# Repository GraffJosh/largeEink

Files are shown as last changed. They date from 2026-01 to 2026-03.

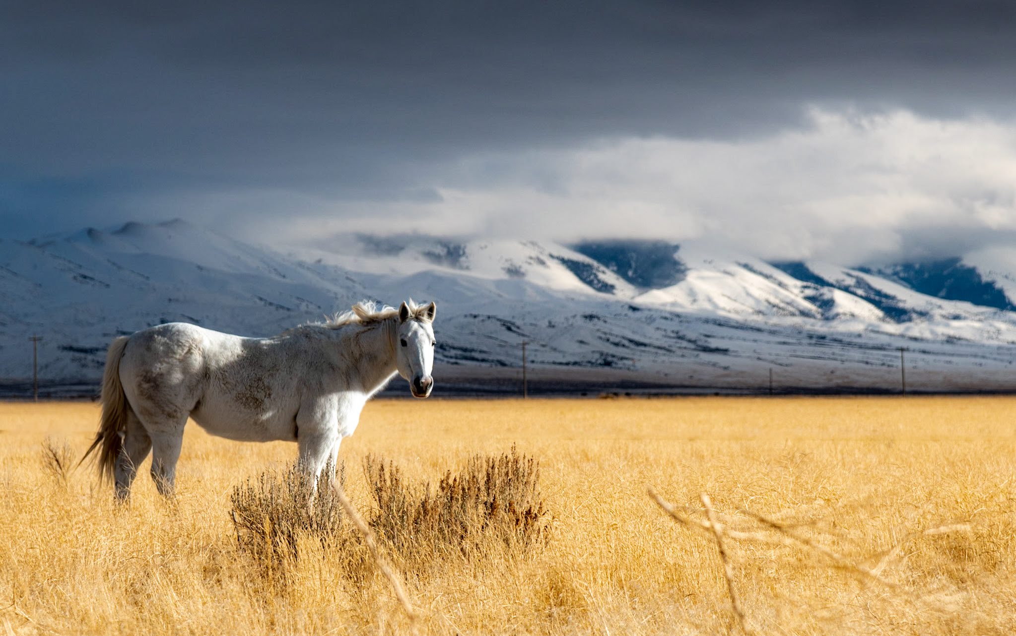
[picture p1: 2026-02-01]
imageServer/images/DSC_2975.jpg

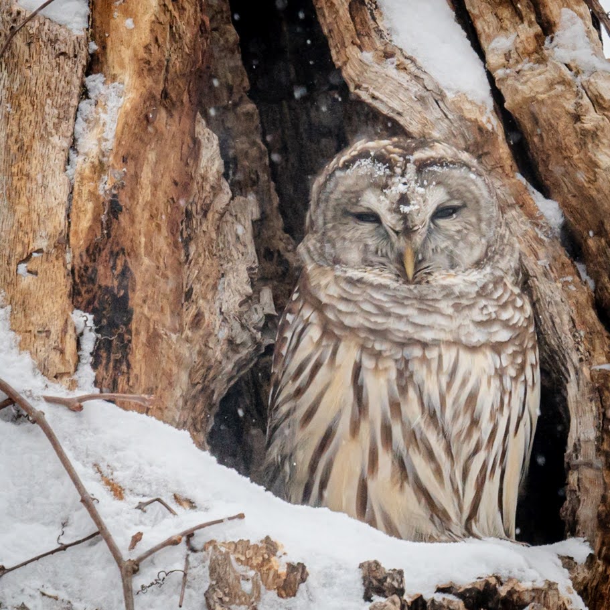
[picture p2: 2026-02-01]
imageServer/images/owl.jpg

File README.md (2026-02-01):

# largeEink — 7.5" E‑Paper Smart Display

Small project to drive a 7.5" grayscale e‑ink panel from an ESP32. Includes:
- An ESP32 firmware (eInkDriver.c) that fetches BMP images, converts to 4‑level grayscale with ordered dither + gamma LUT, and displays them on an e‑paper module.
- A Python helper (convertImage.py) to convert PNG/JPEG images into 4bpp C arrays for embedding.
- MQTT/Home Assistant integration for remote control.





Subscript: I don't like writing docs, so genAI helped with this page. If you're reading this, and you're a human a) I'm surprised you found my project b) I'm happy to help you implement this on your project. 

## Repository layout
- eInkDriver/  
  - eInkDriver.c — main ESP32 firmware
  - convertImage.py — Python tool to convert images to 4bpp C arrays
  - icons.h, secrets.h, other project files (expected)
- imageServer/
  - imageServer.py - serves images over HTTP to the esp32.
  - eInkImage.py - Helper class for the image server (

## Prerequisites
- Hardware: ESP32 board compatible with the e‑paper module used (pins in firmware), 7.5" e‑paper display.
- Toolchain: Arduino/PlatformIO or preferred ESP32 toolchain to compile and flash the C firmware.
- Python 3 + associated image libraris to run the conversion script.
  - Install: pip install pillow

## Configuration
- secrets.h — add WIFI_SSID, WIFI_PASS, MQTT_SERVER, MQTT_PORT, MQTT_USER, MQTT_PASSWORD and any URL constants (URL1, URL2, URL3, etc.).

## Using the Python image converter
Script: convertImage.py
Usage:
python3 convertImage.py <inputDirectory> <OutputFilename> <width> <height>

- inputDirectory: folder with .png/.jpg/.jpeg files.
- OutputFilename: path to the generated C header (appends arrays).
- width/height: desired target size to resize each image to.

The script writes PROGMEM C arrays and width/height constants for each image.

## Firmware behavior
- Downloads BMP image(s) from configured URLs, converts streamed BMP rows to 4bpp via a dithered/gamma LUT, and pushes rows to the display.
- Maintains persistent preferences (imageCount, displayIndex), Reducing unecessary flickering after deep sleep
- Exposes MQTT/Home Assistant entities for page selection, aux URL, refresh, and battery sensors (via HA-MQTT integration).
- Supports deep sleep wake via buttons and timer.

## MQTT / Home Assistant
- Device ID and friendly name defined in eInkDriver.c (HA_DEVICE_ID, HA_DEVICE_FRIENDLY_NAME).
- Provided entities include page selection, aux URL, refresh button and battery sensors. Configure your Home Assistant MQTT discovery or use the included HA‑MQTT helper to register entities.

## Troubleshooting
- BMP download: server must serve uncompressed BMP with expected resolution/pixel format.
- The driver must receive exactly 480x800 pixels image, in 8bit BMP format.

## Tips
- Make sure you setup your secrets file with the correct URLS and credentials for MQTT etc

## Future Work
- It would be cool to do partial updates or less flickering.
  - For example an indicator showing that it's thinking or working.

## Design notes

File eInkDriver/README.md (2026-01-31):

# E-Ink Smart Display Driver

A comprehensive Arduino firmware for an ESP32-based 7.5-inch e-ink display with Home Assistant integration, battery monitoring, and multi-page support.

## Overview

This project drives a large e-ink display with WiFi connectivity, Home Assistant MQTT support, and local image serving. The display supports grayscale dithering, battery-aware deep sleep, and button-controlled page navigation.

## Hardware Requirements

- **Microcontroller**: ESP32 (tested on variant with ADC)
- **Display**: 7.5-inch e-ink panel (800×480 resolution, 4-level grayscale) https://www.seeedstudio.com/TRMNL-7-5-Inch-OG-DIY-Kit-p-6481.html
- **Power**: 4.2V battery with voltage divider to ADC
- **Input**: 3 push buttons on GPIO pins
- **GPIO Pins**:
    - `BUTTON_1_PIN` (D1): Next page
    - `BUTTON_2_PIN` (D2): Refresh current page
    - `BUTTON_3_PIN` (D4): Previous page
    - `BATTERY_PIN` (GPIO1): Battery voltage ADC input
    - `ADC_EN_PIN` (GPIO6): ADC enable control
## Installation Example:



## Software Dependencies

### Arduino Libraries
- `WiFi.h` – Network connectivity
- `HTTPClient.h` – Download images and check updates
- `TFT_eSPI.h` – Display driver library
- `PubSubClient.h` – MQTT client
- `Preferences.h` – Persistent storage (ESP32 NVS)

### Custom Libraries
- `HaMqttEntities.h` – Home Assistant MQTT discovery & entities
- `driver.h` – E-ink display abstraction layer
- `icons.h` – Battery indicator icons (4bpp format)
- `secrets.h` – WiFi and MQTT credentials

## Configuration

### secrets.h Template
Create a `secrets.h` file in the sketch directory:

```cpp
#define WIFI_SSID "your-ssid"
#define WIFI_PASS "your-password"

#define MQTT_SERVER "192.168.1.100"
#define MQTT_PORT 1883
#define MQTT_USER "mqtt_user"
#define MQTT_PASSWORD "mqtt_password"

#define URL1 "http://your-server/path1" 
#define URL2 "http://your-server/path2"
#define URL3 "http://your-server/path3" (This URL is used to determine if there is an updated image; it should return a BMP image counter as plain text. The name should be updated eventually.)
#define URL4 "http://your-server/path4"

#define HA_URL_PREFIX "http://your-server/"
#define HA_URL_SUFFIX ""
#define HA_URL_DATA "default-page"
```

### Display Rotation
Modify `ROTATION` constant (0–3) to adjust display orientation.

## Features

### Multi-Page Display System
Three configurable pages:
- **Page 0 (Image)**: BMP image from server with periodic refresh
- **Page 1 (Home Assistant)**: Dashboard from HA instance
- **Page 2 (Auxiliary)**: Custom URL via MQTT

### Advanced Image Dithering
- **Ordered Bayer dithering** for smooth grayscale representation
- **Gamma correction** with 256-entry lookup table
- **Snap-to-level** logic prevents noise in flat UI areas
- Configurable dither strength (default 85/255)

### Battery Management
- Real-time voltage monitoring (30-sample averaging)
- Battery state classification:
    - `BATT_FULL` (≥4.0V)
    - `BATT_GOOD` (≥3.7V)
    - `BATT_MEDIUM` (≥3.5V)
    - `BATT_LOW` (≥3.2V)
    - `BATT_CRITICAL` (<3.2V)
- Battery icon overlay on display
- Automatic deep sleep when voltage <4.1V

### Deep Sleep & Power Management
- **Deep sleep duration**: 300 seconds (Image page), 200 seconds (others)
- **Wake triggers**: Button press or timer interrupt
- **Power conservation**: ADC disabled between reads, WiFi disconnects during sleep
- **Startup delay**: 20-second minimum awake time before sleep

### Home Assistant Integration
MQTT entities for:
- `page_select` – Page selection dropdown
- `aux_url` – Dynamic auxiliary URL
- `refresh_button` – Manual refresh trigger
- `battery_voltage` – Real-time voltage (V)
- `battery_state` – Battery percentage (%)

Device ID: `smart_display_5`

### Button Controls
- **Button 1**: Cycle to next page
- **Button 2**: Force refresh current page
- **Button 3**: Cycle to previous page
- **Debounce**: 250ms delay between presses

## Image Processing

### BMP Download & Conversion
1. Stream 24-bit BMP from HTTP server
2. Convert to grayscale per-pixel
3. Apply ordered dithering with gamma correction
4. Pack into 4-bit-per-pixel format
5. Push rows to display in reverse order

### Image Server Integration
- Checks server image counter for new content
- Only re-downloads when counter changes
- Image count stored in NVS to persist across reboots

## Building & Uploading

1. Install Arduino IDE with ESP32 board support
2. Add required libraries via Library Manager
3. Create `secrets.h` with your credentials
4. Configure pin assignments if different
5. Select appropriate ESP32 board variant
6. Upload sketch

## Persistent Storage (NVS)

- `displayIndex` – Current page number
- `imageCount` – Last-downloaded image counter

Access via `Preferences` API (namespace: `"myapp"`).

## Troubleshooting

| Issue | Solution |
|---|---|
| Display crashes on startup | Ensure e-ink init before WiFi init |
| WiFi timeout | Check 15-second timeout threshold |
| Dither artifacts | Adjust `SNAP_THRESH` or `DITHER_STRENGTH` |
| Battery reading unstable | Verify voltage divider resistor values |
| MQTT connection fails | Confirm broker address, user, and password |

## Future Enhancements

- Partial display updates for faster refresh
- Compressed image support
- Scheduled updates vs. timer-only
- Home Assistant automations (auto-switch pages)

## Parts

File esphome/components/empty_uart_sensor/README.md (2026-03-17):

```yaml
# example configuration:

sensor:
  - platform: empty_uart_sensor
    name: Empty UART sensor

uart:
  tx_pin: D0
  rx_pin: D1
  baud_rate: 9600
```

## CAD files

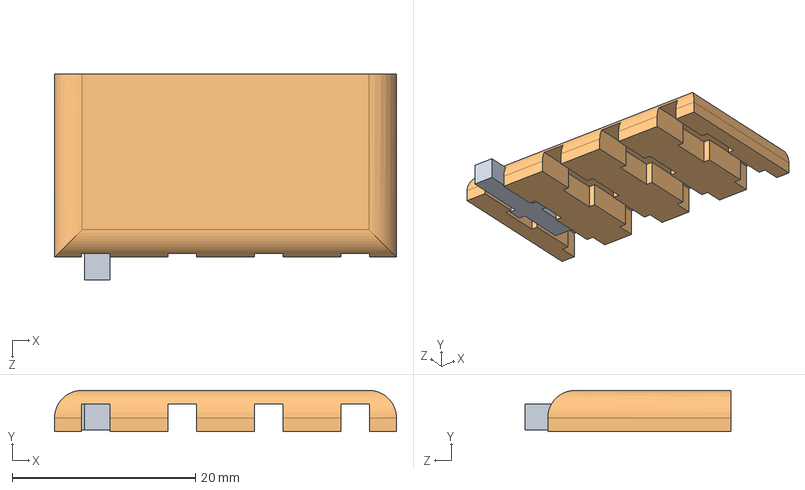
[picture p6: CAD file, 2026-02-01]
Button Pusher Assembly.SLDASM
37.3 x 4.50 x 22.5 mm
Button Adapter
Button

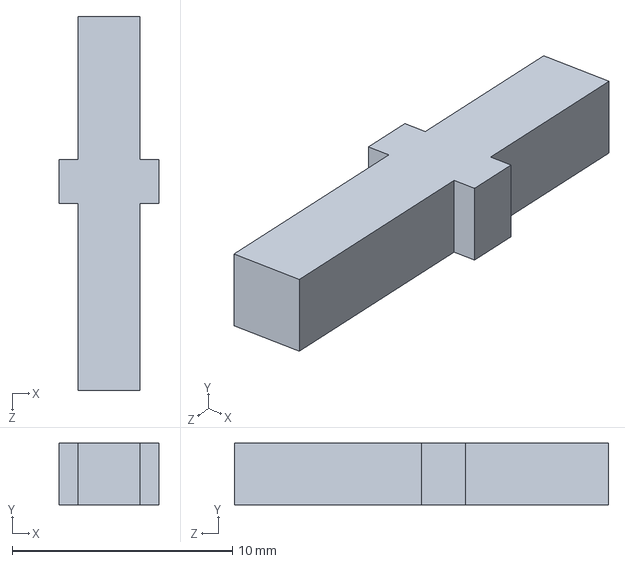
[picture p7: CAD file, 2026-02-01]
Button.SLDPRT
4.55 x 2.80 x 17.0 mm

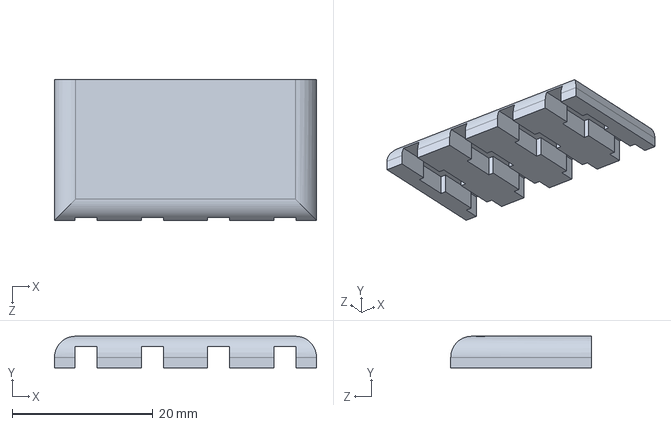
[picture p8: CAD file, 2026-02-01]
Button Adapter.SLDPRT
37.3 x 4.50 x 20.0 mm

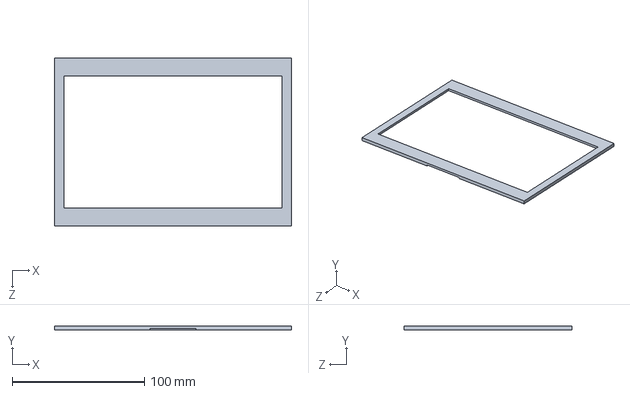
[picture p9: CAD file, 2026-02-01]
Frame Adapter.SLDPRT
179.0 x 3.00 x 127.0 mm

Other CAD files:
Button Adapter.STL
Button.STL
Frame Adapter.STL

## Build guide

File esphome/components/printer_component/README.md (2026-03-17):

```yaml
# example configuration:

empty_uart_component:
  id: empty_uart_component_1

uart:
  tx_pin: D0
  rx_pin: D1
  baud_rate: 9600
```

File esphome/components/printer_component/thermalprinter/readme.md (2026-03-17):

# Epson TM-T88II Library

A Library to control an Epson TM-T88II thermal printer (microprinter) by an arduino via serial connection.

## Requirements

To get Arduino work together with the thermal priner on RS232 (serial) you need a level shifter. From Maxim you can get MAX2XX chips for 5 Volt and MAX32XX for 3.3 volt powered arduinos. The library works with SoftSerial so you are still able to send Data to Arduino with the standard serial line. The SoftSerial works at 9600 baud.

## Tested

- Epson TM-T88II Model M129B (Serial RS232) & Arduino Uno & Maxim MAX233CPP

## Functions

The functions available in this class are:

### `Epson::Epson(int rxPin, int txPin)`

Constructor that initializes the `rxPin` and `txPin` used to communicate with the printer and calls the `start()` function.

### `void Epson::start()`

Sets up the communication pins, initializes the `SoftwareSerial` object used for communication with the printer, and sets the baud rate to 9600.

### `int Epson::getStatus()`

Sends a query to the printer to check its status. Returns `22` if the printer is online.

### `int Epson::read()`

Reads a single byte of data from the printer.

### `void Epson::feed(uint8_t n)`

Prints the data in the print buffer and feeds `n` lines of paper.

### `void Epson::feed()`

Equivalent to calling `feed(1)`.

### `void Epson::lineSpacing(uint8_t n)`

Sets the line spacing to `n/180` inch.

### `void Epson::defaultLineSpacing()`

Sets the line spacing to `1/6` inch, which is equivalent to 30 dots.

### `void Epson::characterSet(uint8_t n)`

Selects an international character set based on the value of `n`. See reference for more metails.

Example:

```
 0 = U.S.A.
 1 = France
 2 = Germany
 3 = U.K.
 4 = Denmark I
 5 = Sweden
 6 = Italy
 7 = Spain
 8 = Japan
 9 = Norway
10 = Denmark II
```

### `void Epson::doubleHeightOn()`

Enables double-height text printing.

### `void Epson::doubleHeightOff()`

Disables double-height text printing.

### `void Epson::boldOn()`

Enables bold text printing.

### `void Epson::boldOff()`

Disables bold text printing.

### `void Epson::underlineOn()`

Enables underlined text printing.

### `void Epson::underlineOff()`

Disables underlined text printing.

### `void Epson::reverseOn()`

Enables white/black reverse printing mode.

### `void Epson::reverseOff()`

Disables white/black reverse printing mode.

### `void Epson::justifyLeft()`

Sets text justification to left.

### `void Epson::justifyCenter()`

Sets text justification to center.

### `void Epson::justifyRight()`

Sets text justification to right.

### `void Epson::barcodeHeight(uint8_t n)`

Sets the height of barcodes to `n` dots. Range 1-255.

### `void Epson::barcodeWidth(uint8_t n)`

Sets the width of barcodes to `n` dots. Range 2-6

### `void Epson::barcodeNumberPosition(uint8_t n)`

Sets the position of the barcode number. Range 0-3

### `void Epson::printBarcode(uint8_t m, uint8_t n)`

Prints a barcode of type `m` (range 65-73) with a digit length of `n`.

### `void Epson::cut()`

Performs a full cut of the paper.

### `size_t Epson::write(uint8_t c)`

Writes a single byte of data to the printer.

## Inspiration

- [Tom Taylor · Post Microprinter](https://web.archive.org/web/20130116063826/http://tomtaylor.co.uk/projects/microprinter)
- [Tom Taylor · Code for the microprinter project](https://github.com/tomtaylor/microprinter-arduino)
- [Roo Reynolds · Post Microprinter](http://rooreynolds.com/2009/02/01/microprinter/)
- [Roo Reynolds · Microprinter Arduino library, Java and Ruby API](https://github.com/rooreynolds/microprinter)
- [Adafruit · Mini Thermal Receipt Printers](https://learn.adafruit.com/mini-thermal-receipt-printer)
- [Adafruit · Thermal Printer Library](https://github.com/adafruit/Adafruit-Thermal-Printer-Library/)

## Contributors

- [docwisdom](https://github.com/docwisdom)
- [signalwerk](https://github.com/signalwerk)

Contributions appreciated.

## License

You may use this work under the terms of either the MIT License or the GNU General Public License (GPL) Version 3

## History

- 2023-03-02 - Add a documentation of the class to the readme.md
- 2014-11-24 - include functionality for reading printer status, printing barcodes and justification
- 2012-04-13 - first public release
- 2012-03-13 - first beta of the class extracted for standalone
- 2010-06-05 – first public lecture with the code ([«Der Tag der Schrift»](http://www.typo-online.ch/tds/2010/))

### Keywords

thermal, micro, receipt, printer, serial, tm-t88, tm88, tmt88, epson

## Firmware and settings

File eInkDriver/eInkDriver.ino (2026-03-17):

#include <WiFi.h>
#include <HTTPClient.h>
#include "TFT_eSPI.h"
#include "driver.h"
#include <Preferences.h>
#include "secrets.h"
#include "icons.h"

#include<PubSubClient.h>
#include<HaMqttEntities.h>



Preferences prefs;
EPaper epaper;

const char* ssid = WIFI_SSID;
const char* password = WIFI_PASS;

const char* url1 = URL1;
const char* url2 = URL2;
const char* url3 = URL3;

const uint8_t ROTATION = 2; // Rotation of 2 rotates 180

#define SRC_W 800
#define SRC_H 480
#define DST_W 800
#define DST_H 480

#define BYTES_PER_ROW (DST_W / 2)
#define IMAGE_SIZE (BYTES_PER_ROW * DST_H)

// 256-entry lookup table
static uint8_t gammaLUT[256];
static const uint8_t bayer8[8][8] = {
 { 0,48,12,60, 3,51,15,63},
 {32,16,44,28,35,19,47,31},
 { 8,56, 4,52,11,59, 7,55},
 {40,24,36,20,43,27,39,23},
 { 2,50,14,62, 1,49,13,61},
 {34,18,46,30,33,17,45,29},
 {10,58, 6,54, 9,57, 5,53},
 {42,26,38,22,41,25,37,21}
};

uint32_t lastUpdateMs = 0, startupTime=0;
uint16_t updateCount = 0;
uint32_t imageCount = 0;
uint8_t displayIndex = 0;
bool freshBoot = true;
bool deepsleepEnabled = false;
bool imageUpdateComplete = true;
uint16_t deepSleepDurationSeconds = 300;

const float CALIBRATION_FACTOR = 0.968;
#define BATTERY_PIN 1       // GPIO1 (A0) - BAT_ADC
#define ADC_EN_PIN 6        // GPIO6 (A5) - ADC_EN

const int BUTTON_1_PIN = D1;  // First user button
const int BUTTON_2_PIN = D2;  // Second user button
const int BUTTON_3_PIN = D4;  // Third user button
volatile bool button1Pressed = false;
volatile bool button2Pressed = false;
volatile bool button3Pressed = false;
#define BUTTON_DEBOUNCE_TIME_MS 250

WiFiClient client;
PubSubClient mqtt_client(client);


enum PageSelection{
    PAGE_IMAGE,
    PAGE_HOMEASSISTANT,
    PAGE_AUX_PAGE,
    PAGE_NUMPAGES
};
const char * select_options[PAGE_NUMPAGES] PROGMEM = {
     "Image Page",
     "HA Page",
     "Aux Page"
     };
     
const char * page_urls[PAGE_NUMPAGES] PROGMEM = {
     URL2,
     URL1,
     URL4,
     };

enum BatteryState{
    BATT_FULL,
    BATT_GOOD,
    BATT_MEDIUM,
    BATT_LOW,
    BATT_CRITICAL,
}batteryStatus;

#define HA_DEVICE_ID            "smart_display_5"
#define HA_DEVICE_FRIENDLY_NAME "7.5in Epaper Smart Display"

#define ENTITIES_COUNT 5
HADevice ha_device = HADevice(HA_DEVICE_ID,HA_DEVICE_FRIENDLY_NAME,"1.0");
// HANumber haPageNumber = HANumber("page_num","Page Number",ha_device,1,100,1);
HASelect haPageSelect = HASelect("page_select","Page Select",ha_device,PAGE_NUMPAGES,select_options);
HAText haURL = HAText("aux_url","Aux URL",ha_device,150);
HAButton haRefreshButton = HAButton("refresh_button","Refresh Page",ha_device);
HASensorNumeric haBatteryVoltage = HASensorNumeric("battery_voltage","Battery Voltage",ha_device,"V",2);
HASensorNumeric haBatteryState = HASensorNumeric("battery_state","Battery State",ha_device,"%",0);
// HASensorBinary haDeepSleepActive = HASensorBinary("deep_sleep_active","Deep Sleep Active");
// HASensorBinary haDeviceOnline = HASensorBinary("device_online","Device Online");


int getPageIndexFromSelect(const char* receivedSelectState,const char** list, uint16_t listSize)
{
    for(int index=0;index<listSize;index++)
    {
        if(!strcmp(list[index],receivedSelectState))
        {
            return index;
        }
    }
    return -1;
}

/* Callback from HA-MQTT entities. It is called when an entity changes its state.

    Entity can be NULL when the received topic is not related to any entity.
    This is useful to handle other topics with the same mqtt client.
*/
void ha_callback(HAEntity *entity, char *topic, byte *payload, unsigned int length){
    // if(entity == &haPageNumber){
    //     Serial.printf("Changed number state to %d \n",haPageNumber.getState());
    // }
    // else 
    if(entity == &haPageSelect)
    {
        printf("HA Callback set %s\n",haPageSelect.getState());
        setDisplayIndex(haPageSelect.getState());
    }
    else if(entity == &haRefreshButton)
    {
        Serial.printf("Refresh Button Pressed\n");
        freshBoot = true;
    }
    else if(entity == &haURL)
    {
        String prefix(HA_URL_PREFIX);
        String suffix(HA_URL_SUFFIX);
        String data(haURL.getState());
        static String auxURL = (prefix + data + suffix);
        page_urls[PAGE_AUX_PAGE] = auxURL.c_str();
        Serial.printf("Loading new Aux URL: %s\n",page_urls[PAGE_AUX_PAGE]);
        haURL.setState(data.c_str());
        setDisplayIndex(PAGE_AUX_PAGE);
        freshBoot = true;
    }
    else
        Serial.println("Callback called from other subscription");

}

/*
 * Display index handles which page we're currently displaying. 
 * These helpers ensure that the value is stored in persistent memory
 * (to reduce boot up updates)
 */
int getDisplayIndex()
{
    return prefs.getInt("displayIndex",PAGE_HOMEASSISTANT);
}
void setDisplayIndex(const char* receivedSelectState)
{
    Serial.printf("Select state: %s\n",receivedSelectState);
    int pageIndex = getPageIndexFromSelect(receivedSelectState,select_options,PAGE_NUMPAGES);
    if(pageIndex == -1)
    {
        Serial.printf("Failed to extract page index from state?\n");
    }
    else
    {
        setDisplayIndex(pageIndex);
        Serial.printf("Page Index updated to: %d\n",pageIndex);
    }
}
void setDisplayIndex(PageSelection index)
{
    setDisplayIndex((int) index);
}
void setDisplayIndex(int index)
{
    prefs.putInt("displayIndex", index);
    haPageSelect.setState(select_options[index]);
}
void incrementDisplayIndex()
{
    int next_page = (getDisplayIndex()+1);
    if(next_page == PAGE_NUMPAGES)
    {
        next_page = 0;
    }
    setDisplayIndex(next_page);
    Serial.printf("Increment Page to: %d\n",(int)next_page);
}
void decrementDisplayIndex()
{
    int next_page = (getDisplayIndex()-1);
    if(next_page < 0)
    {
        next_page = PAGE_NUMPAGES - 1;
    }
    setDisplayIndex(next_page);
    Serial.printf("Decrement Page to: %d\n",(int)next_page);
}

/*
 * Helper functions to compute time for deepsleep
 */
constexpr uint64_t deepSleepSeconds(uint64_t s) {
  return s * 1000000ULL;
}
constexpr uint64_t deepSleepMinutes(uint64_t m) {
  return deepSleepSeconds(m * 60ULL);
}

//ISR for handling buttons
void IRAM_ATTR button1ISR()
{    
    button1Pressed = true; 
}
void IRAM_ATTR button2ISR()
{    
    button2Pressed = true; 
}
void IRAM_ATTR button3ISR()
{    
    button3Pressed = true; 
}

#define ADC_SAMPLES 30
#define ADC_COUNTS 4095.0
#define ADC_REF_VOLTAGE 3.6
#define VOLTAGE_DIVIDER 2.0
float readBatteryVoltage() {
    // Enable ADC
    digitalWrite(ADC_EN_PIN, HIGH);
    delay(10);  // Short delay to stabilize

    // Read 30 times and average for more stable readings
    long sum = 0;
    for(int i = 0; i < ADC_SAMPLES; i++) {
        sum += analogRead(BATTERY_PIN);
        delayMicroseconds(100);
    }

    // Disable ADC to save power
    digitalWrite(ADC_EN_PIN, LOW);

    // Calculate voltage
    float adc_avg = sum / (ADC_SAMPLES*1.0);
    float voltage = (adc_avg / ADC_COUNTS) * ADC_REF_VOLTAGE * VOLTAGE_DIVIDER * CALIBRATION_FACTOR;

    // Determine battery level
    if (voltage >= 4.0) {
        batteryStatus = BATT_FULL;
    } else if (voltage >= 3.7) {
        batteryStatus = BATT_GOOD;
    } else if (voltage >= 3.5) {
        batteryStatus = BATT_MEDIUM;
    } else if (voltage >= 3.2) {
        batteryStatus = BATT_LOW;
    } else {
        batteryStatus = BATT_CRITICAL;
    }
    haBatteryVoltage.setState(voltage);
    haBatteryState.setState(map(voltage,4.2,3.1,100,0));
    return voltage;
}
// Call this once in setup() to initialize the LUT
void setupGammaLUT(float gamma = 0.4) {
    for (int i = 0; i < 256; i++) {
        float normalized = i / 255.0f;             // 0..1
        float corrected = pow(normalized, 1.0f / gamma);  // gamma correction
        uint8_t level = corrected * 4;             // 0..3
        if (level > 3) level = 3;                  // clamp
        gammaLUT[i] = level;
    }
}
// Nominal centers of each gray level (tune if needed)
#define G0  0     // black
#define G1  85    // dark gray
#define G2  170   // light gray
#define G3  255   // white

#define SNAP_THRESH 1   // +/- range to lock in (tune this!)

uint8_t ditheredLevel(uint8_t gray, int x, int y)
{
    // ----- PHASE 1: SNAP INPUT VALUES TO KNOWN-GOOD LEVELS -----
    // If the incoming pixel value is already very close to one of the
    // canonical gray centers (black, dark gray, light gray, white),
    // we lock it to that level immediately and skip dithering entirely.
    //
    // This prevents dithering noise in flat areas like text, icons,
    // UI backgrounds, and large uniform regions.
    if (abs(gray - G0) <= SNAP_THRESH) return 0;  // Near black → force black
    if (abs(gray - G1) <= SNAP_THRESH) return 1;  // Near dark gray → force level 1
    if (abs(gray - G2) <= SNAP_THRESH) return 2;  // Near light gray → force level 2
    if (abs(gray - G3) <= SNAP_THRESH) return 3;  // Near white → force white

    // ----- PHASE 2: ORDERED DITHER THRESHOLD LOOKUP -----
    // Look up a value from the 8×8 Bayer matrix using the pixel's (x, y)
    // coordinates. The "(x + y)" term decorrelates columns so that
    // vertical banding does not appear on the e-ink panel.
    //
    // The Bayer matrix values are in the range 0–63.
    int t = bayer8[y & 7][(x + y) & 7];

    // Shift the Bayer value so it is centered around zero.
    // This converts the range:
    //     0–63  →  -32…+31
    //
    // Centering is important so the dither adds *positive and negative*
    // bias evenly around the original pixel value.
    t -= 32;

    // ----- PHASE 3: APPLY DITHER AS A SMALL BIAS -----
    // Each output gray level is separated by ~85 (255 / 3).
    // We scale the dither so it nudges the pixel by roughly ±½
    // of one quantization step (~±42).
    //
    // This is enough to push pixels across level boundaries
    // without creating visible structure or banding.
    int adjusted = gray + (t * 85) / 64;

    // Clamp the adjusted value to the valid 8-bit grayscale range
    // to prevent underflow or overflow.
    if (adjusted < 0)   adjusted = 0;
    if (adjusted > 255) adjusted = 255;

    // ----- PHASE 4: SNAP AGAIN AT THE EXTREMES -----
    // After dithering, the adjusted value might drift slightly
    // into or out of the black/white regions. We re-snap here
    // to ensure that true blacks and whites remain stable and
    // do not acquire dither noise at their edges.
    if (adjusted <= G0 + SNAP_THRESH) return 0;  // Force black
    if (adjusted >= G3 - SNAP_THRESH) return 3;  // Force white

    // ----- PHASE 5: FINAL QUANTIZATION -----
    // Convert the final 8-bit grayscale value into one of the
    // 4 e-ink gray levels (0–3) using the gamma correction LUT.
    //
    // This LUT handles panel-specific response nonlinearity.
    return gammaLUT[adjusted];
}

void downloadAndConvertBMP(const char* url) {
    
    HTTPClient http;
    Serial.println("Starting BMP Download and Conversion.");
    http.setTimeout(60000);  // 30 seconds
    // http.setBufferSize(1024);  // or smaller
    http.setReuse(false);
    http.setRedirectLimit(10);
    http.begin(client, url);
    int code = http.GET();
    if (code != 200) {
        Serial.printf("HTTP GET failed: %d\n", code);
        Serial.printf("Content-Length: %d\n", http.getSize());
        Serial.printf("HTTP Code: %d\n", code);
        Serial.printf("Transfer-Encoding: %s\n", http.header("Transfer-Encoding").c_str());
        http.end();
        return;
    }

    WiFiClient* stream = http.getStreamPtr();
    if (!stream) {
        Serial.println("Failed to get stream");
        http.end();
        return;
    }

    uint8_t junk[32];
    // Read BITMAPFILEHEADER (14 bytes)
    uint8_t fileHeader[14];
    if (stream->readBytes(fileHeader, 14) != 14) {
        Serial.println("Failed to read BMP file header");
        return;
    }

    // Extract pixel data offset
    uint32_t bfOffBits = *(uint32_t*)&fileHeader[10];

    // We already consumed 14 bytes
    uint32_t toSkip = bfOffBits - 14;

    // Skip DIB header + palette (whatever size)
    while (toSkip > 0) {
        uint16_t n = stream->readBytes(junk, min(toSkip, (uint32_t)sizeof(junk)));
        if (n == 0) {
            Serial.println("Failed skipping BMP header/palette");
            return;
        }
        toSkip -= n;
    }

    // Process row by row
    uint16_t rowStride = (SRC_W + 3) & ~3; // BMP row padded to 4 bytes
    uint16_t padding = rowStride - SRC_W;
    // Row buffer
    static uint8_t grayRow[SRC_W];
    static uint8_t row4bpp[DST_W/2];
    static uint8_t level0 = 0;
    static uint8_t level1 = 0;
    static uint8_t packed = 0;
    // Read the BMP Image row by row, starting from the bottom. 
    for (int y = 0; y < DST_H; y++) {
        // 1. Read one BMP row into grayRow[SRC_W]
        stream->readBytes(grayRow, SRC_W);
        
        /* 2. Convert 2x8-bit → 2x4-level → 4bpp packed
        *      This is confusing, but it is a proprietary (and perhaps industry) standard for
        *      packing images for the Eink. The library mandates 4 bits per pixel, even though 
        *      it is only 2 bits of information (4 levels of gray)
        */
        for (int x = 0; x < DST_W; x += 2) {
        //    uint8_t level0 = gammaLUT[grayRow[x]];       // first pixel
        //    uint8_t level1 = gammaLUT[grayRow[x + 1]];   // second pixel
        //    uint8_t packed = (level0 << 4) | (level1 & 0x0F); // pack 2 pixels into 1 byte
        //    row4bpp[x / 2] = packed;

            level0 = ditheredLevel(grayRow[x],     x,     y);
            level1 = ditheredLevel(grayRow[x + 1], x + 1, y);

            packed = (level0 << 4) | (level1 & 0x0F);
            row4bpp[x / 2] = packed;
        }
        
        // 3. Push this row to the display in reversed y order
        epaper.pushImage(0, DST_H - 1 - y, DST_W, 1, (uint16_t*) row4bpp, 4);
        if (y % 100 == 0) Serial.printf("Processed row %d\n", y);
        
        // 4. Skip padding. This is poorly tested, because most rows aren't padded.
        if (padding) {
            stream->readBytes(junk, padding);
        }
    }
    addBatteryIndicator();
    //Write to the display
    epaper.update();
    
    // updateScreenInChunks(128);
    //This var is for future use if we ever succeed with partial updates.
    updateCount++;
    // Write persistent memory with image count, indicating that we've successfully displayed the image.
    prefs.putInt("imageCount",imageCount);

    while (stream->available()) {
        uint8_t tmp[256];
        stream->readBytes(tmp, min(stream->available(), (int)sizeof(tmp)));
    }

    Serial.println("BMP streamed and converted to 4-bit buffer");
    http.end();  // safe
}
void updateScreenInChunks(int chunkSize) {
    for (int y = 0; y < DST_H; y += chunkSize) {
        for (int x = 0; x < DST_W; x += chunkSize) {

            int w = chunkSize;
            int h = chunkSize;

            // Clamp width/height at screen edges
            if (x + w > DST_W) w = DST_W - x;
            if (y + h > DST_H) h = DST_H - y;

            epaper.updataPartial(x, y, w, h);
        }
    }
}

void addBatteryIndicator()
{
    uint16_t iconHeight=50,iconWidth = 50;
    uint16_t* icon;
    switch(batteryStatus){
        // case BATT_FULL:
        //     iconWidth = battery_charging_iconWidth;
        //     iconHeight = battery_charging_iconHeight;
        //     icon = (uint16_t*) battery_charging;
        //     break;
        // case BATT_GOOD:
        //     iconWidth = battery_90_iconWidth;
        //     iconHeight = battery_90_iconHeight;
        //     icon = (uint16_t*) battery_90;
        //     break;
        // case BATT_MEDIUM:
        //     iconWidth = battery_50_iconWidth;
        //     iconHeight = battery_50_iconHeight;
        //     icon = (uint16_t*) battery_50;
        //     break;
        case BATT_LOW:
            iconWidth = battery_50_iconWidth;
            iconHeight = battery_50_iconHeight;
            icon = (uint16_t*) battery_50;
            break;
        case BATT_CRITICAL:
            iconWidth = battery_10_iconWidth;
            iconHeight = battery_10_iconHeight;
            icon = (uint16_t*) battery_10;
            break;
    }
    if(icon != NULL)
    {
        uint16_t xpos = TFT_WIDTH-(15+iconWidth);
        uint16_t ypos = TFT_HEIGHT-(15+iconWidth);
        epaper.fillCircle(xpos+(iconWidth/2), ypos+(iconHeight/2), iconHeight, TFT_GRAY_0);
        epaper.pushImage(xpos,ypos,iconWidth,iconHeight, icon);
    }
}

/*
 * Ping a server to get the image index, which should increment every time the image on the server updates.
 * This pairs with the custom image server written for this device.
 * Returns True if the local image counter doesn't match the server image counter.
 * Retruns False if the local image counter matches the server's image counter (indicating no new image)
 */

bool checkForNewImage(const char* url)
{
    HTTPClient http;
    // WiFiClient client;

    Serial.println("Checking Server for new image.");

    http.setTimeout(30000);
    http.setReuse(false);
    http.setRedirectLimit(10);

    if (!http.begin(client, url)) {
        return false;
    }

    int code = http.GET();
    if (code != 200) {
        Serial.printf("HTTP GET failed: %d\n", code);
        http.end();
        return false;
    }

    // Read response safely
    char imageCountStr[16] = {0};
    size_t idx = 0;

    while (client.connected() || client.available()) {
        if (client.available()) {
            char c = client.read();
            if (idx < sizeof(imageCountStr) - 1) {
                imageCountStr[idx++] = c;
            }
        }
        delay(1);  // yield to LWIP
    }

    http.end();  // ALWAYS

    int serverImageCount = atoi(imageCountStr);

    Serial.printf(
        "Checked for new image, received %s\n",
        (serverImageCount != imageCount) ? "New Image Ready" : "No New Image Ready"
    );

    if (serverImageCount != imageCount) {
        imageCount = serverImageCount;
        Serial.println("New image is ready at the server.");
        return true;
    }

    return false;
}
// Broke this out into a helper in case I ever want to light-sleep
void initWifi()
{
    uint32_t start = millis();
    WiFi.begin(ssid, password);
    while (WiFi.status() != WL_CONNECTED) {
        delay(500);
        Serial.print(".");
        if (millis() - start > 30000) {
            initDeepSleep();
        }
    }
    Serial.println("Wifi Initialized.");
}
void initMqtt()
{
    mqtt_client.setServer(MQTT_SERVER, MQTT_PORT);

    HAMQTT.begin(mqtt_client,ENTITIES_COUNT);
    // HAMQTT.addEntity(haPageNumber);
    // haPageNumber.setState(displayIndex);
    HAMQTT.addEntity(haPageSelect);
    HAMQTT.addEntity(haURL);
    HAMQTT.addEntity(haRefreshButton);
    HAMQTT.addEntity(haBatteryState);
    HAMQTT.addEntity(haBatteryVoltage);
    // HAMQTT.addEntity(haDeepSleepActive);
    // HAMQTT.addEntity(haDeviceOnline);


    haPageSelect.setState(select_options[displayIndex]);
    haURL.setState(HA_URL_DATA);

    HAMQTT.setCallback(ha_callback);
    Serial.printf("MQTT initialized\n");
}
void initDeepSleep()
{

    // haDeviceOnline.setState(false);
    #define WAKE_MASK ((1ULL << BUTTON_1_PIN) | (1ULL << BUTTON_2_PIN) | 1ULL << BUTTON_3_PIN)
    esp_sleep_enable_ext1_wakeup(WAKE_MASK, ESP_EXT1_WAKEUP_ALL_LOW);
    esp_sleep_enable_timer_wakeup(deepSleepSeconds(deepSleepDurationSeconds));
    esp_deep_sleep_start();
}
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
void loop() {
    handleButtons();
    checkMqtt();
    if(shouldUpdateDisplay()) updateDisplay();
    if(shouldDeepSleep()) initDeepSleep();
    delay(period);
}

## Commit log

2026-01-28 Add files. Currently displays two pages, one homeassistant page, one image served by the image server.
2026-01-29 Rename driver file, add example image server (hopefully)
2026-01-31 Conditionally display battery icon
2026-02-01 Add image server to repository
    [Button Adapter.SLDPRT, Button Adapter.STL, Button Pusher Assembly.SLDASM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]
2026-02-01 Fix HA Entities bug.
    [eInkDriver.ino]
2026-02-01 Fix MQTT Crashing bug
    [eInkDriver.ino]
